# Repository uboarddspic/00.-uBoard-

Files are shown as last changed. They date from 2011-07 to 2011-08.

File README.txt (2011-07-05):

// info //
// Source code
This is the latest version of the source code.
On top of each C file is the version number.
The projects can be opened in MPLAB with the C30 compiler.
And also with the MPLAB X IDE.
Please visit www.uboard.eu for updates.

// Bootloader
Also included is the bootloader for the uBoard. 
The uBoard comes with a pre-programmed microcontroller. 
If you have bought the dSPic33FJ64GP802 somewhere else, 
you have to load the uBoard bootloader.hex with a 
traditional programmer like the ICD3 or Pickit3.

// How to use //
At startup, the uBoard is in bootloader mode.
You can load any program.

Compatible with Windows XP, Vista & Windows 7.
Copyright Staronic (C) 2010
Downloaded from www.uBoard.eu

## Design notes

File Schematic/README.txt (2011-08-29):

When creating your own hardware for the uboard, draw your design in this schematic. You can easily stack your pcb at the bottom of the uBoard for rapid prototyping.

Please open in Eagle 5.0.0

Copyright Staronic (C) 2011
Downloaded from www.uBoard.eu

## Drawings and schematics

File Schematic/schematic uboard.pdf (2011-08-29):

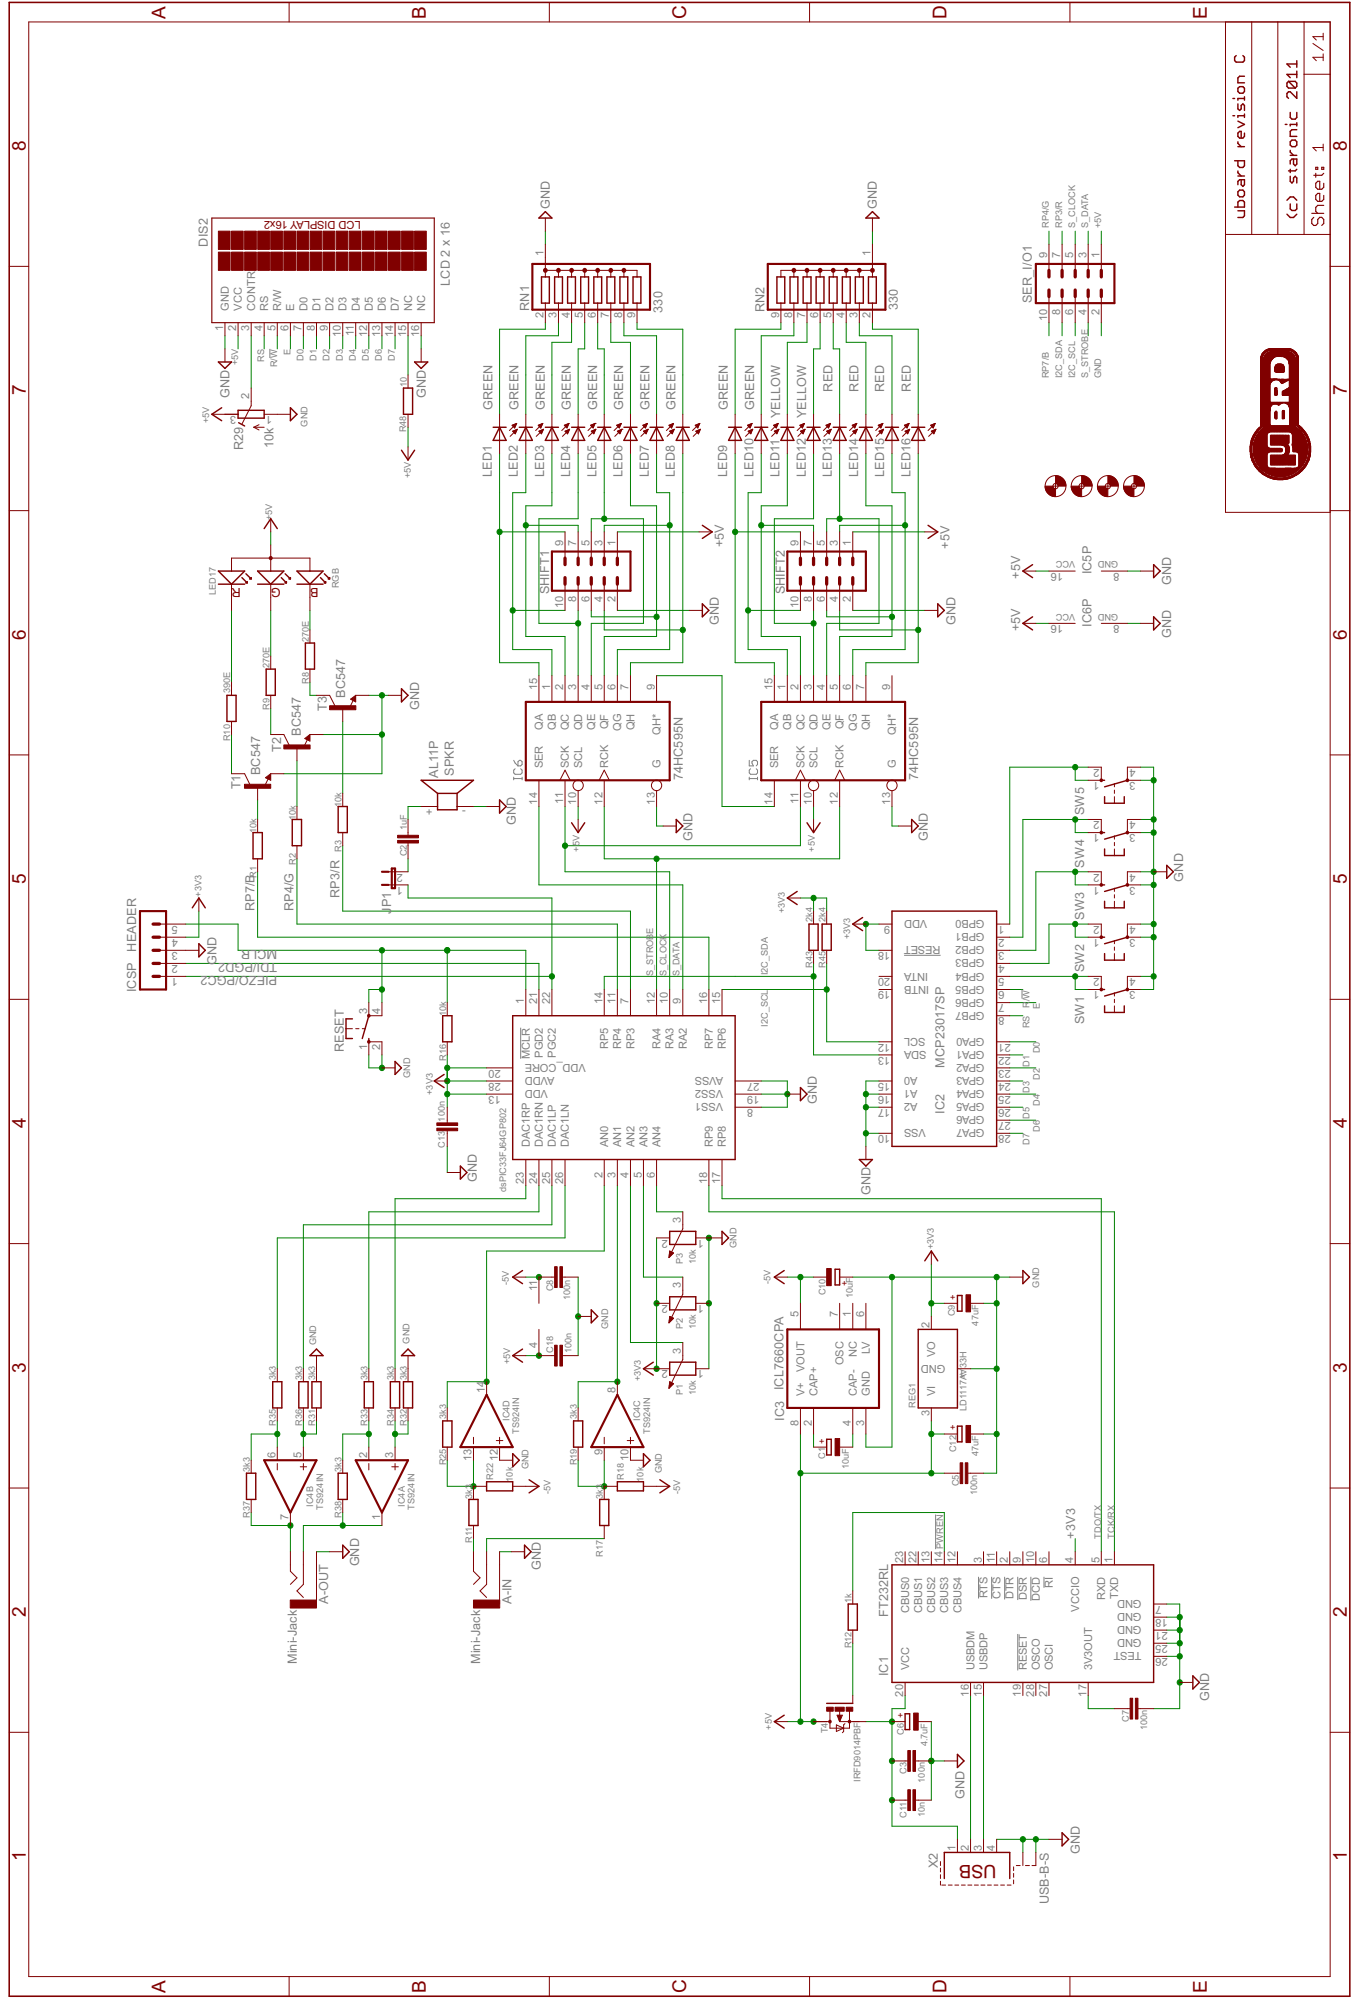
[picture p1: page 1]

R G B + + + ABCDE 1 2 3 4 5 6 7 8 ABCDE 1 2 3 4 5 6 7 8 BSU 2x61 YALPSI D DCL ++ Mini-Jack RED R8 R10 1 3 2 4 SW1 R16 R17 R1 R8 19 R11 R2 R2 25 3 12 4 RESET 1 3 2 4 SW2 R31 R32 R33 R34 R35 R36 R37 R38 LED17 R9 C18 C11 LV 6 CAP- 4 NC 1 VOUT 5 GND 3 V+ 8 OSC 7 CAP+ 2IC3 T4 C3 C5 C6C7 R12 C1 C8 VI 3 VO 2 DNG 1 REG1 VCC 20 3V3OUT 17 USBDP 15 USBDM 16 OSCO 28 OSCI 27 DNG 7 TXD 1 RXD 5 RTS 3 CTS 11 DTR 2 DSR 9 DCD 10 RI 6 CBUS0 23 CBUS1 22 CBUS2 13 CBUS3 14 CBUS4 12 VCCIO 4 RESET 19 DNG 52 DNG 81 TSET 62 DNG 12 IC1 C10 LCS 21 ADS 31 0A 51 1A 61 2A 71 TESER 81 ATNI 02 BTNI 91 0BPG 1 1BPG 2 2BPG 3 3BPG 4 4BPG 5 5BPG 6 6BPG 7 7BPG 8 0APG 12 1APG 22 2APG 32 3APG 42 4APG 52 5APG 62 6APG 72 7APG 82 DDV 9 SSV 01 IC2 23 1 IC4A 65 7 IC4B 910 8 IC4C 1312 14 IC4D 4 11 MCLR 1 AN0 2 AN1 3 AN2 4 AN3 5 AN4 6 RP3 7 1SSV 8 RA2 9 RA3 10 RP4 11 RA4 12 DDV 31 RP5 14 RP6 15 RP7 16 RP8 17 RP9 18 2SSV 91 EROC_DDV 02 PGD2 21 PGC2 22 DAC1RP 23 DAC1RN 24 DAC1LP 25 DAC1LN 26 SSVA 72 DDVA 82dsPIC33FJ64GP802 1 3 2 4 SW3 1 3 2 4 SW4 1 3 2 4 SW5 3 1 2 R29 R43 R45 2 1 3 P1 2 1 3 P2 2 1 3 P3 1234 X2 LED1 LED2 LED3 LED4 LED5 LED6 LED7 LED9 LED10 LED11 LED12 LED13 LED14 LED15 LED16 LED8 GND 1 VCC 2 CONTR 3 RS 4 R/W 5 E 6 D0 7 D1 8 D2 9 D3 10 D4 11 D5 12 D6 13 D7 14 NC 15 NC 16 DIS2 QB 1 QC 2 QD 3 QE 4 QF 5 QG 6 QH 7 SCL 10 SCK 11 RCK 12 G 13 SER 14 QA 15 QH* 9 61 8 CCV DNG IC5P QB 1 QC 2 QD 3 QE 4 QF 5 QG 6 QH 7 SCL 10 SCK 11 RCK 12 G 13 SER 14 QA 15 QH* 9 61 8 CCV DNG IC6P R48 + - SPKR C2 12345 ICSP 1 2 3 4 5 6 7 8 9 10 SER_I/O1 1 2 3 4 5 6 7 8 9 10SHIFT1 1 2 3 4 5 6 7 8 9 10SHIFT2 C9 C12 C13 T1 T2 T3 A-IN A-OUT 1 23456789RN1 1 98765432RN2 R1R2R3 12 JP1 GND TCK/RX 2 DGP/I DT TDO/TX S_DATA S_DATA S_STROBE S_STROBE +3V3 +5V +5V PWREN I2C_SCL I2C_SCL I2C_SDA I2C_SDA S_CLOCK S_CLOCK RS RS R/W R/W E E D7 D7 D6 D6 D5 D5 D4 D4 D3 D3 D2 D2 D1 D1 D0 D0 RP4/G RP4/G RP3/R RP3/R RP7/B RP7/B RL CM 2 CGP/ OZEI P GND GND 270E 390E GND GND GND GND GND 10k 3k3 10k 3k3 3k3 10k 3k3 GND GND GND GND +3V3 +3V3 +3V3 3k3 3k3 3k3 3k3 3k3 3k3 GND GND 3k3 3k3 RGB 270E 100n 10n +5V GND +3V3 ICL7660CPA IRFD9014PBF 100n 100n 4.7uF100n 1k GND GND 10uF 100n LD1117AV33H FT232RL 10uF MCP23017SP -5V -5V +5V TS924IN TS924IN TS924IN TS924IN -5V -5V +3V3 +5V 10k +5V GND 2k4 2k+43V3 10k 10k 10k GND USB-B-S GREEN GREEN GREEN GREEN GREEN GREEN GREEN GREEN GREEN YELLOW YELLOW RED RED RED GREEN GND LCD 2 x 16 GND GND GND 74HC595N 74HC595N GND GND +5V +5V +5V +5V 10 AL11P 1uFGND +5V GND +5V GND +5V HEADER 47uF 47uF 100n GND GND GND BC547BC547BC547 Mini-Jack 330 330 10k10k10k GND

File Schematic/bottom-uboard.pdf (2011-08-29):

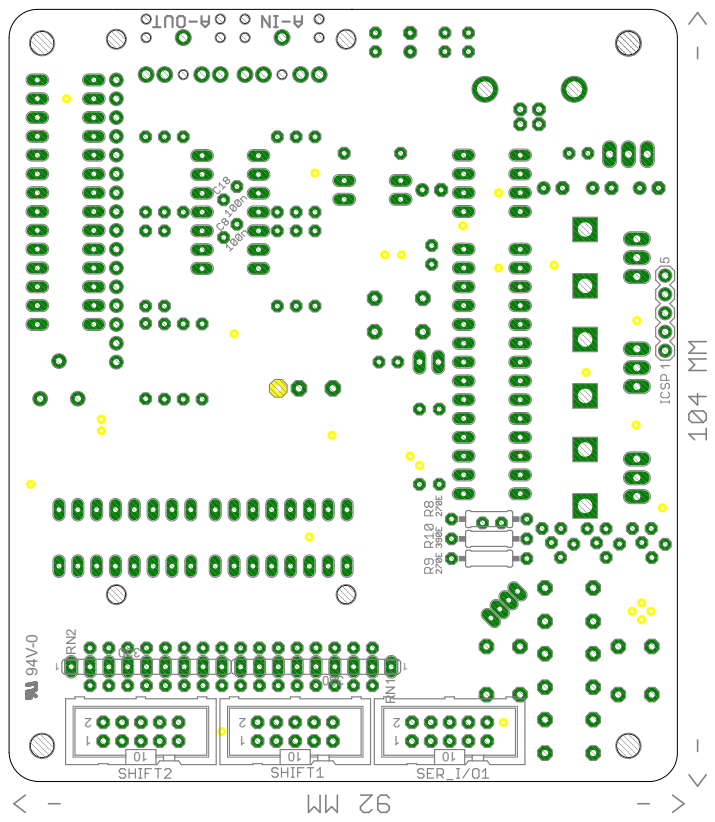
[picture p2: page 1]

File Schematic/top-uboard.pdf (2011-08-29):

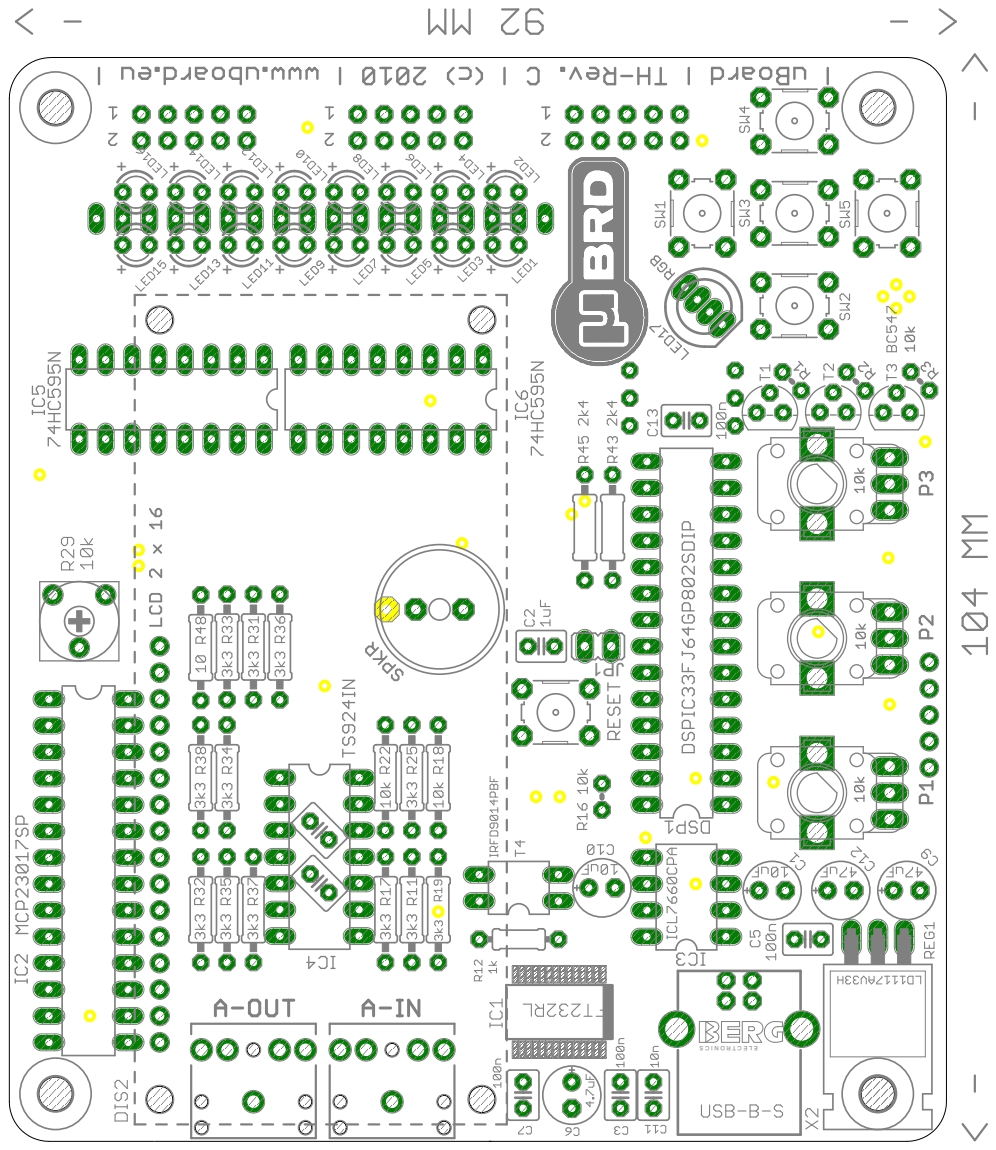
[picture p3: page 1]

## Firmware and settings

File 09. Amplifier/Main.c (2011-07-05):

///////////////////////////////////////////////////////////////////////////
//  Product/Project : Amplifier                                          //
///////////////////////////////////////////////////////////////////////////
//
//  File Name    : Main.c
//  Version      : 1.0
//  Description  : Use the potmeters to set the amplification and show 
//				   this on VU meter leds
//  Author       : Jim Clermonts
//  Target       : dsPIC33FJ64GP802
//  Compiler     : MPLAB C Compiler for PIC24 and dsPIC v3.25 in LITE mode
//  IDE          : MPLAB X IDE Beta4.0
//  Programmer   : uBRD bootloader
//  Last Updated : 09-01-2011
//
//  Copyright (c) Staronic 2011.
//  All rights are reserved. Reproduction in whole or in part is
//  prohibited without the written consent of the copyright owner.
///////////////////////////////////////////////////////////////////////////
#include    "Delay.h"
#include    "Peripherals.h"
#include    "uBRD.h"

//Configuration-for-programmer--------------------------
_FBS(RBS_NO_RAM & BSS_NO_FLASH & BWRP_WRPROTECT_OFF);               // No boot ram, flash, write protection
_FSS(RSS_NO_RAM & SWRP_WRPROTECT_OFF);                              // No protected sections
_FGS(GSS_OFF & GCP_OFF & GWRP_OFF);                                 // No code protection
_FOSCSEL(FNOSC_FRCPLL & IESO_OFF);                                  // FRC Oscillator with PLL, no two-speed oscillator
_FOSC(FCKSM_CSDCMD & IOL1WAY_OFF & OSCIOFNC_ON  & POSCMD_NONE);     // Clock Switching and Fail Safe Clock Monitor is disabled
                                                                    // Multiple I/O reconfigurations admitted                                                                  // OSC2 Pin is digital I/O														                      // Primaire Oscillator Mode: none
_FWDT(FWDTEN_OFF & WINDIS_OFF);                                     // Watchdog Timer off
_FPOR(ALTI2C_ON & FPWRT_PWR64);                                     // 64 ms power-up timer
_FICD(JTAGEN_OFF & ICS_PGD2);                                       // JTAG program port off
//------------------------------------------------------

struct
{
    // DMA buffer for A/D converter results
    int ADC1_0; // S/H channel 0: potmeter right
    int ADC1_1; // S/H channel 1: audio left
    int ADC1_2; // S/H channel 2: audio right
    int ADC1_3; // S/H channel 3: potmeter left
} DMAbuffer __attribute__((space(dma)));

#define	FIRST	500
#define	DIFF	500

void VU_meter_amp(unsigned short l,unsigned short r)
{
    unsigned short lvu, rvu;

    // Convert number to led value
    lvu = 0;
    if (l > FIRST + 0 * DIFF) lvu = VU_A1;
    if (l > FIRST + 1 * DIFF) lvu = VU_A2;
    if (l > FIRST + 3 * DIFF) lvu = VU_A3;
    if (l > FIRST + 6 * DIFF) lvu = VU_A4;
    if (l > FIRST + 10 * DIFF) lvu = VU_A5;
    if (l > FIRST + 15 * DIFF) lvu = VU_A6;
    if (l > FIRST + 21 * DIFF) lvu = VU_A7;
    if (l > FIRST + 28 * DIFF) lvu = VU_A8;
    rvu = 0;
    if (r > FIRST + 0 * DIFF) rvu = VU_B1;
    if (r > FIRST + 1 * DIFF) rvu = VU_B2;
    if (r > FIRST + 3 * DIFF) rvu = VU_B3;
    if (r > FIRST + 6 * DIFF) rvu = VU_B4;
    if (r > FIRST + 10 * DIFF) rvu = VU_B5;
    if (r > FIRST + 15 * DIFF) rvu = VU_B6;
    if (r > FIRST + 21 * DIFF) rvu = VU_B7;
    if (r > FIRST + 28 * DIFF) rvu = VU_B8;

    Shiftleds(lvu | rvu);
}

void Init_ADC_amp(void)
{
    AD1PCFGL = 0xFFE0; // AN0-AN4 analog inputs
    AD1CON1 = 0x11EC; // A/D module disabled
    /* 	10-bit conversion
            Signed integer format
            Auto-convert mode
            Simultaneous sampling
            Sampling starts automatic
     */
    AD1CSSL = 0x0000; // No input scanning
    AD1CON3 = 0x0203; // Systemclock for ADC
    /* 	Sampletime 3*Tad
            Tad 4*Tcy (100 ns)
            Sampletime = 4*12*Tad+Tsamp = 51 Tad = 5.1 us (200ks/s)
     */
    AD1CON2 = 0x0200; // AVdd and AVss as ADC reference voltages
    AD1CON4 = 0x0000; // 1 word buffer for each analog input
    AD1CHS123 = 0x0000; // Vref- as negative input
    /* 	AN0 = S/H channel 1 positive input (audio left)
            AN1 = S/H channel 2 positive input (audio right)
            AN2 = S/H channel 3 positive input (potmeter left)
     */
    AD1CHS0 = 0x0003; // Vref- as negative input
    // AN3 = S/H channel 0 positive input (potmeter right)
}

void Init_DAC_amp(void)
{
    DMA0CON = 0x0020;
    /* 	DMA channel disabled
        Mode: peripheral indirect, continuous, no ping-pong
     */
    DMA0PAD = (int) &ADC1BUF0; // DMA address = ADC1BUF0
    DMA0CNT = 3; // 4 DMA requests: 4 buffers, each 1 word
    DMA0REQ = 13; // ADC1 = DMA request source
    DMA0STA = __builtin_dmaoffset(&DMAbuffer);
    // Start DMA and A/D modules
    DMA0CONbits.CHEN = 1; // Enable DMA
    AD1CON1bits.ADON = 1; // Start A/D module
    // Initialize D/A convertor
    ACLKCONbits.SELACLK = 0; // Fast RC with PLL as aux. osc. divider source (80 MHz)
    ACLKCONbits.ASRCSEL = 1; // Primair oscillator as aux. osc. source
    ACLKCONbits.APSTSCLR = 0b111; // Aux. oscillator divider 1
    DAC1CONbits.DACFDIV = 3; // DAC clock divider 4
    DAC1DFLT = 0x0000; // Default value
    DAC1CONbits.FORM = 1; // Signed integer
    DAC1STATbits.LOEN = 1; // Left output enabled
    DAC1STATbits.ROEN = 1; // Right output enabled
    DAC1CONbits.DACEN = 1; // Start D/A module
}

int main(void)
{
    int i;
    int l, r, lmax = 0, rmax = 0;
    long l_offset = 0, r_offset = 0;

    Init_port();
    Init();
    Init_timers();
    Init_ADC_amp();
    Init_DAC_amp();

    while (1)
    {
        // Wait untill conversion = complete
        while (!IFS0bits.DMA0IF)
        {
            DAC(l, r);
        }
        // Erase DMA flag
        IFS0bits.DMA0IF = 0;

        // New DAC values
        // +512 because ADC format = signed integer
        l = (DMAbuffer.ADC1_1 - r_offset) * ((DMAbuffer.ADC1_3 + 512) >> 3);
        // +512 because ADC format = signed integer
        r = (DMAbuffer.ADC1_2 - l_offset) * ((DMAbuffer.ADC1_0 + 512) >> 3);
        DAC(l, r);

        // Peak detection
        if (l > lmax) lmax = l;
        if (r > rmax) rmax = r;

        if (i++ > 10000)
        {
            VU_meter_amp(lmax, rmax);
            setRGB(lmax >> 7, 0, rmax >> 7);
            i = 0;
            lmax = 0;
            rmax = 0;
        }
    }
    return (0);
}

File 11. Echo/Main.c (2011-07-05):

///////////////////////////////////////////////////////////////////////////
//  Product/Project : Echo                                               //
///////////////////////////////////////////////////////////////////////////
//
//  File Name    : Main.c
//  Version      : 1.0
//  Description  : Press the down switch to toggle echo on/off
//  Author       : Jim Clermonts
//  Target       : dsPIC33FJ64GP802
//  Compiler     : MPLAB C Compiler for PIC24 and dsPIC v3.25 in LITE mode
//  IDE          : MPLAB X IDE Beta4.0
//  Programmer   : uBRD bootloader
//  Last Updated : 16-01-2011
//
//  Copyright (c) Staronic 2011.
//  All rights are reserved. Reproduction in whole or in part is
//  prohibited without the written consent of the copyright owner.
///////////////////////////////////////////////////////////////////////////
#include    "Delay.h"
#include    "Peripherals.h"
#include    "uBRD.h"

//Configuration-for-programmer--------------------------
_FBS(RBS_NO_RAM & BSS_NO_FLASH & BWRP_WRPROTECT_OFF);               // No boot ram, flash, write protection
_FSS(RSS_NO_RAM & SWRP_WRPROTECT_OFF);                              // No protected sections
_FGS(GSS_OFF
& GCP_OFF & GWRP_OFF);                                              // No code protection
_FOSCSEL(FNOSC_FRCPLL & IESO_OFF);                                  // FRC Oscillator with PLL, no two-speed oscillator
_FOSC(FCKSM_CSDCMD & IOL1WAY_OFF & OSCIOFNC_ON  & POSCMD_NONE);     // Clock Switching and Fail Safe Clock Monitor is disabled
                                                                    // Multiple I/O reconfigurations admitted                                                                  // OSC2 Pin is digital I/O														                      // Primaire Oscillator Mode: none
_FWDT(FWDTEN_OFF & WINDIS_OFF);                                     // Watchdog Timer off
_FPOR(ALTI2C_ON & FPWRT_PWR64);                                     // 64 ms power-up timer
_FICD(JTAGEN_OFF & ICS_PGD2);                                       // JTAG program port off
//------------------------------------------------------

#define ISR __attribute__((interrupt))
// 40.000 kHz sample rate: 8000/40.000=0,2 sec delay
#define BUFFER 	8000 	

unsigned char c;
unsigned char last_c;
unsigned char count = 0;
unsigned char echo_on = 0;
unsigned int i = 0;
char lbuf[BUFFER] __attribute__((far));
char rbuf[BUFFER] __attribute__((far));

void __attribute__((interrupt, auto_psv)) ISR _T2Interrupt(void)
{  
	AD1CHS0bits.CH0SA = 0b00000;    // AN0 = channel 0
    AD1CON1bits.SAMP = 1;           // Start sampling
    while (AD1CON1bits.DONE == 0);  // Wait untill conversion is complete

    if (echo_on)
    {
		// Create the echo
        DAC1RDAT = (ADC1BUF0 << 3)+(rbuf[i] << 7); 
    } 
	else
    {
		// Send input to output, no echo
        DAC1RDAT = ADC1BUF0 << 3; 
    }

	// Store samples
    rbuf[i] = ADC1BUF0 >> 4; 

	// AN1 = channel 0
    AD1CHS0bits.CH0SA = 0b00001;    
	// Start sampling
    AD1CON1bits.SAMP = 1;           
	// Wait untill conversion complete
    while (AD1CON1bits.DONE == 0);  

    if (echo_on)
    {
		// Create the echo
        DAC1LDAT = (ADC1BUF0 << 3)+(lbuf[i] << 7);
    } else
    {
		//// Send input to output, no echo
        DAC1LDAT = ADC1BUF0 << 3; 
    }
	// Store samples
    lbuf[i] = ADC1BUF0 >> 4;

    if (i >= (BUFFER - 1))
    {
        i = 0;
    }
    else
    {
        i++;
    }

    if (count >= 10)
    {
        count = 0;
    }
    else
    {
        count++;
    }
	// Timer2 Interrupt flag low
    IFS0bits.T2IF = 0; 
}

int main(void)
{
    // Initialize digital I/O
    T_LEDR;
    LEDR = 1;
    T_LEDB;
    LEDB = 0;

    Init_port();
    Init();
    Init_timer_echo();
    Init_DAC_echo();
    Init_ADC_echo();
    Init_mcp();

    while (1)
    {
        if (count == 0)
        {
            // Check if switch is pressed
            last_c = c;
            c = Read23X08_17(GPIOB,PORTEXP_UBRD);
        }
        // Delay for switch
        if (count == 10)
        {
            if (((c & 0b00000001) == 0) && (c != last_c))
            {
				// Toggle echo modus
                echo_on =! echo_on; 
				// Blue led is on when echo is activated
                LEDB = !LEDB;
				// Else red led on
                LEDR = !LEDR;
            }
        }
    }
}

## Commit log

2011-07-05 Source code for all on-board peripherals. Working, tested and validated.
2011-08-29 Added schematic and breakout board
    [uBoard breakoutboard.brd, uBoard breakoutboard.sch]
2011-09-11 Minor bugfix for RS232
    [Peripherals.c]
